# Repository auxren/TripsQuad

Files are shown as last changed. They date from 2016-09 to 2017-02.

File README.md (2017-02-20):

# TripsQuad
Eurorack quad wavefolder PCB files and Altium Project

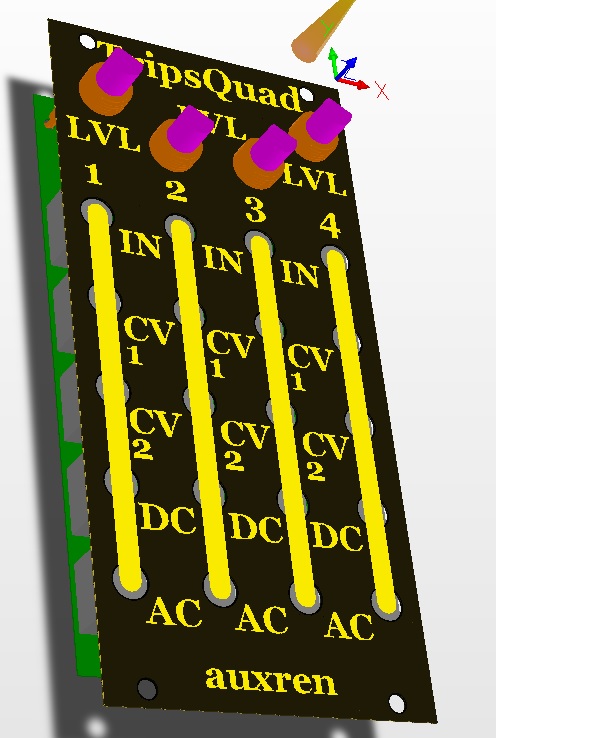
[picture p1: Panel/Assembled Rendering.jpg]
Optional Title


Mouser Cart: http://www.mouser.com/ProjectManager/ProjectDetail.aspx?AccessID=a7427f16d1 

The build is great for beginners learning how to surface mount solder. All the passives are 0805 and there is only 1 IC with a pretty wide pitch.

Note: The trim pots can go on either side; it's up to you. To adjust the trim pots, input a saw wave. Measure the voltage of the signal going in to a channel and adjust the corresponding channel's trim pot so the output has the same voltage.

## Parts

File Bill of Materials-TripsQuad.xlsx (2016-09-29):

Comment | Description | Designator | Supplier P/N | Supplier | Quantity
100pF | CAP 0.5pF 25V ±0.1pF 0805 (2012 Metric) Thickness 0.75mm SMD | C1, C2, C7, C8 | 80-C0805C101J5G (http://www.mouser.com/ProductDetail/Kemet/C0805C101J5GACTU/) | Mouser | 4
47uF | Aluminum Electrolytic Capacitor, 47 uF +/- 20%, 25 V, -55 to 105 degC, 2-Pin 5.3 x 5.3 x 6.1 mm SMD, RoHS, Tape and Reel | C3, C5, C9, C11 | 667-EEE-FT1E470AR | Mouser | 4
470nF | CAP 0.5pF 25V ±0.1pF 0805 (2012 Metric) Thickness 0.75mm SMD | C4, C6, C10, C12 | 581-080516C474K | Mouser | 4
10uF | Aluminum Electrolytic Capacitor, UD Series, Low Impedance, 10 uF, 25 V, + / - 20%, -55 to 105 degC, Chip Type, 4 x 5.8 mm D x L, Pb-Free, Reel | C13 | 810-C4532X7R1E106M | Mouser | 1
100nF | CAP 0.5pF 25V ±0.1pF 0805 (2012 Metric) Thickness 0.75mm SMD | C14, C15 | 581-FS051C104K4Z2A | Mouser | 2
20k | Trimming Potentiometer, 5K Ohm +/- 10%, -55 to 125 degC, 3-Pin 19.05 x 4.83 x 6.6 mm THD, Transparent Housing, RoHS | CH1, CH2, CH3, CH4 | 652-3006P-1-203-LF (http://www.mouser.com/ProductDetail/Bourns/3006P-1-203LF/?qs=sGAEpiMZZMvygUB3GLcD7rufck0TIBKyQNa0Y0kLqn4%3d) | Mouser | 4
1N4148W | Fast Switching Diode, 75 V, 150 mA, 2-Pin 2.7 x 1.6 x 1.25 mm SMD, Tape and Reel | D1, D2, D3, D4, D5, D6, D7, D8, D9, D10, D11, D12, D13, D14, D15, D16 | 833-1N4148W-TP (http://www.mouser.com/ProductDetail/Micro-Commercial-Components-MCC/1N4148W-TP/) | Mouser | 16
1N5819HW-7-F | 1.0 A Surface Mount Schottky Barrier Rectifier, 40 V, -65 to 125 degC, 2-Pin SOD-123 Package, RoHS, Tape and Reel | D17, D18 | 621-1N5819HW-F | Mouser | 2
Thonkicon jack |  | J1, J2, J3, J4, J5, J6, J7, J8, J9, J10, J11, J12, J13, J14, J15, J16, J17, J18, J19, J20 | Mouser: 858-P0915NEC15BR100K also works | Thonk, earthenvar, ect. | 20
100k Pots |  | P1, P2, P3, P4 |  | Thonk, earthenvar, ect. | 4
Header 5X2 | Header, 5-Pin, Dual row | P5 | 855-M20-9980545 (http://www.mouser.com/ProductDetail/Harwin/M20-9980545/) | Mouser | 1
1M5 | 1M5 0.125W 5% 0805 (2012 Metric) SMD | R1, R2, R3, R4, R13, R14, R17, R18, R20, R21, R29, R31 | 667-ERJ-6ENF1504V (http://www.mouser.com/ProductDetail/Panasonic/ERJ-6ENF1504V/?qs=sGAEpiMZZMtG0KNrPCHnjTg0x5DoQJ5P9A0uxp6gV1o%3d) | Mouser | 12
100K | 100K 0.125W 5% 0805 (2012 Metric) SMD | R5, R6, R15, R16, R19, R23, R30, R32 | 755-ESR10EZPJ104 (http://www.mouser.com/ProductDetail/ROHM-Semiconductor/ESR10EZPJ104/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) | Mouser | 8
330R | 330R 0.125W 5% 0805 (2012 Metric) SMD | R7, R8, R22, R25 | 755-ESR10EZPF3300 (http://www.mouser.com/ProductDetail/ROHM-Semiconductor/ESR10EZPF3300/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) | Mouser | 4
220K | 220K 0.125W 5% 0805 (2012 Metric) SMD | R9, R10, R24, R27 | 755-ESR10EZPF2203 (http://www.mouser.com/ProductDetail/ROHM-Semiconductor/ESR10EZPF2203/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) | Mouser | 4
150K | 150K 0.125W 5% 0805 (2012 Metric) SMD | R11, R12, R26, R28 | 755-ESR10EZPF1503 (http://www.mouser.com/ProductDetail/ROHM-Semiconductor/ESR10EZPF1503/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) | Mouser | 4
LM3900 |  | U1 | 595-LM3900DR (http://www.mouser.com/ProductDetail/Texas-Instruments/LM3900DR/?qs=sGAEpiMZZMtYFXwiBRPs06z3mIi0P6Vt) | Mouser | 1

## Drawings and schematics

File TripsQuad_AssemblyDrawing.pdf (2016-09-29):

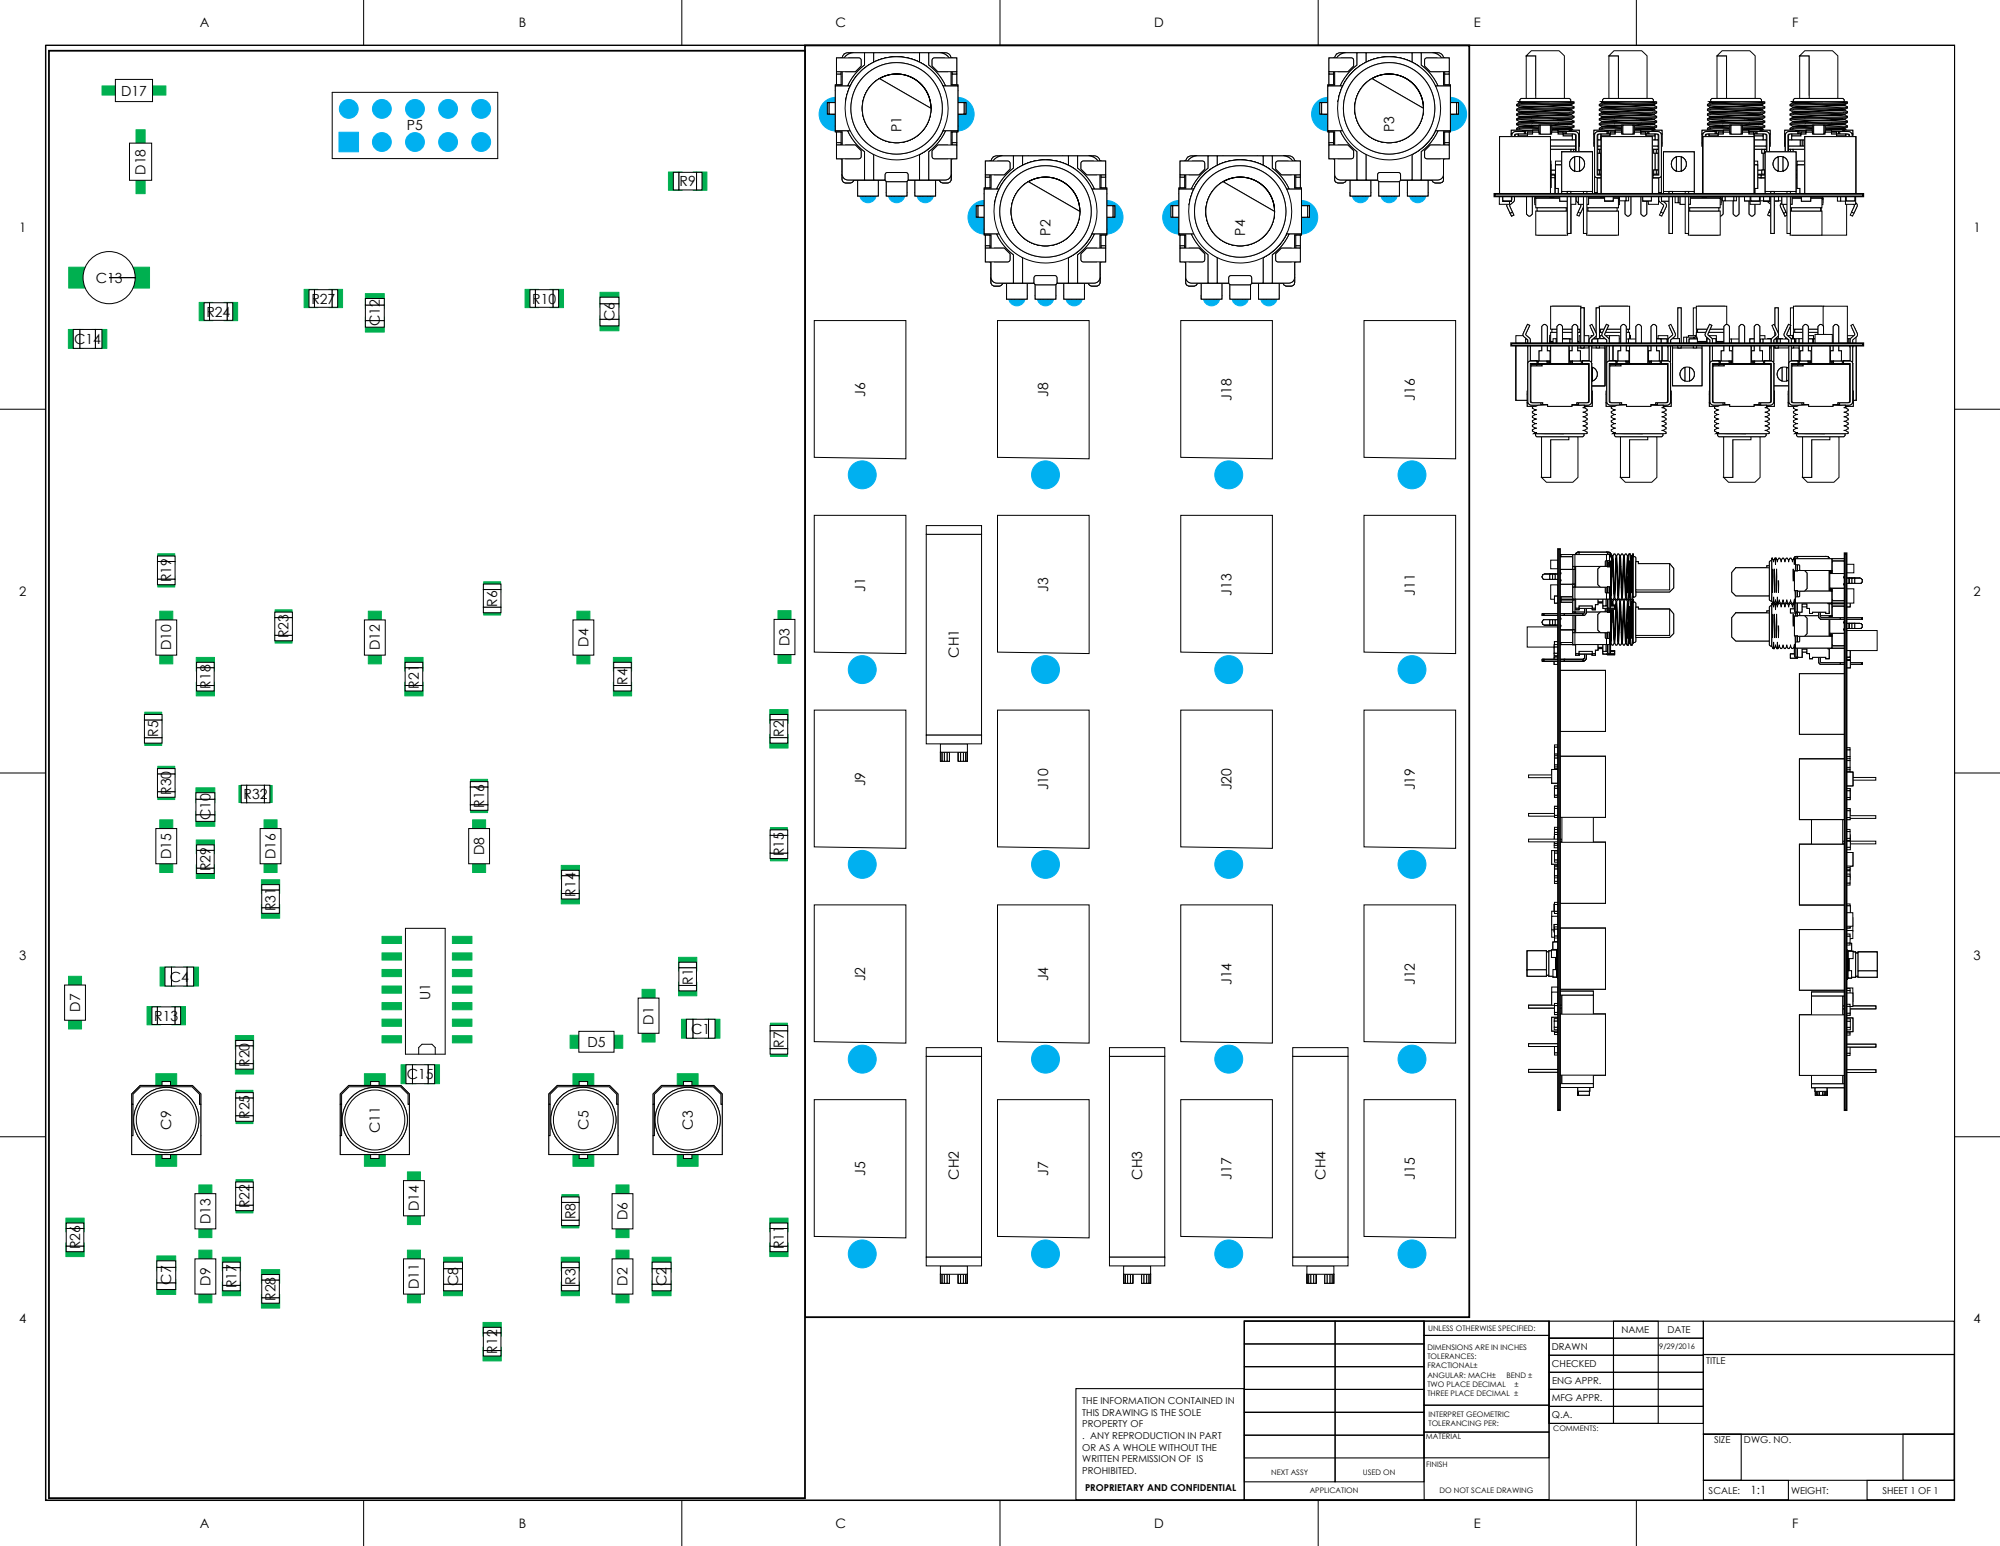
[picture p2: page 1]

DIMENSIONS ARE IN INCHES
TOLERANCES:
FRACTIONAL±
ANGULAR: MACH± BEND ±
TWO PLACE DECIMAL ±
THREE PLACE DECIMAL ±

THE INFORMATION CONTAINED IN
THIS DRAWING IS THE SOLE
PROPERTY OF
. ANY REPRODUCTION IN PART
OR AS A WHOLE WITHOUT THE
WRITTEN PERMISSION OF IS
PROHIBITED.
PROPRIETARY AND CONFIDENTIAL

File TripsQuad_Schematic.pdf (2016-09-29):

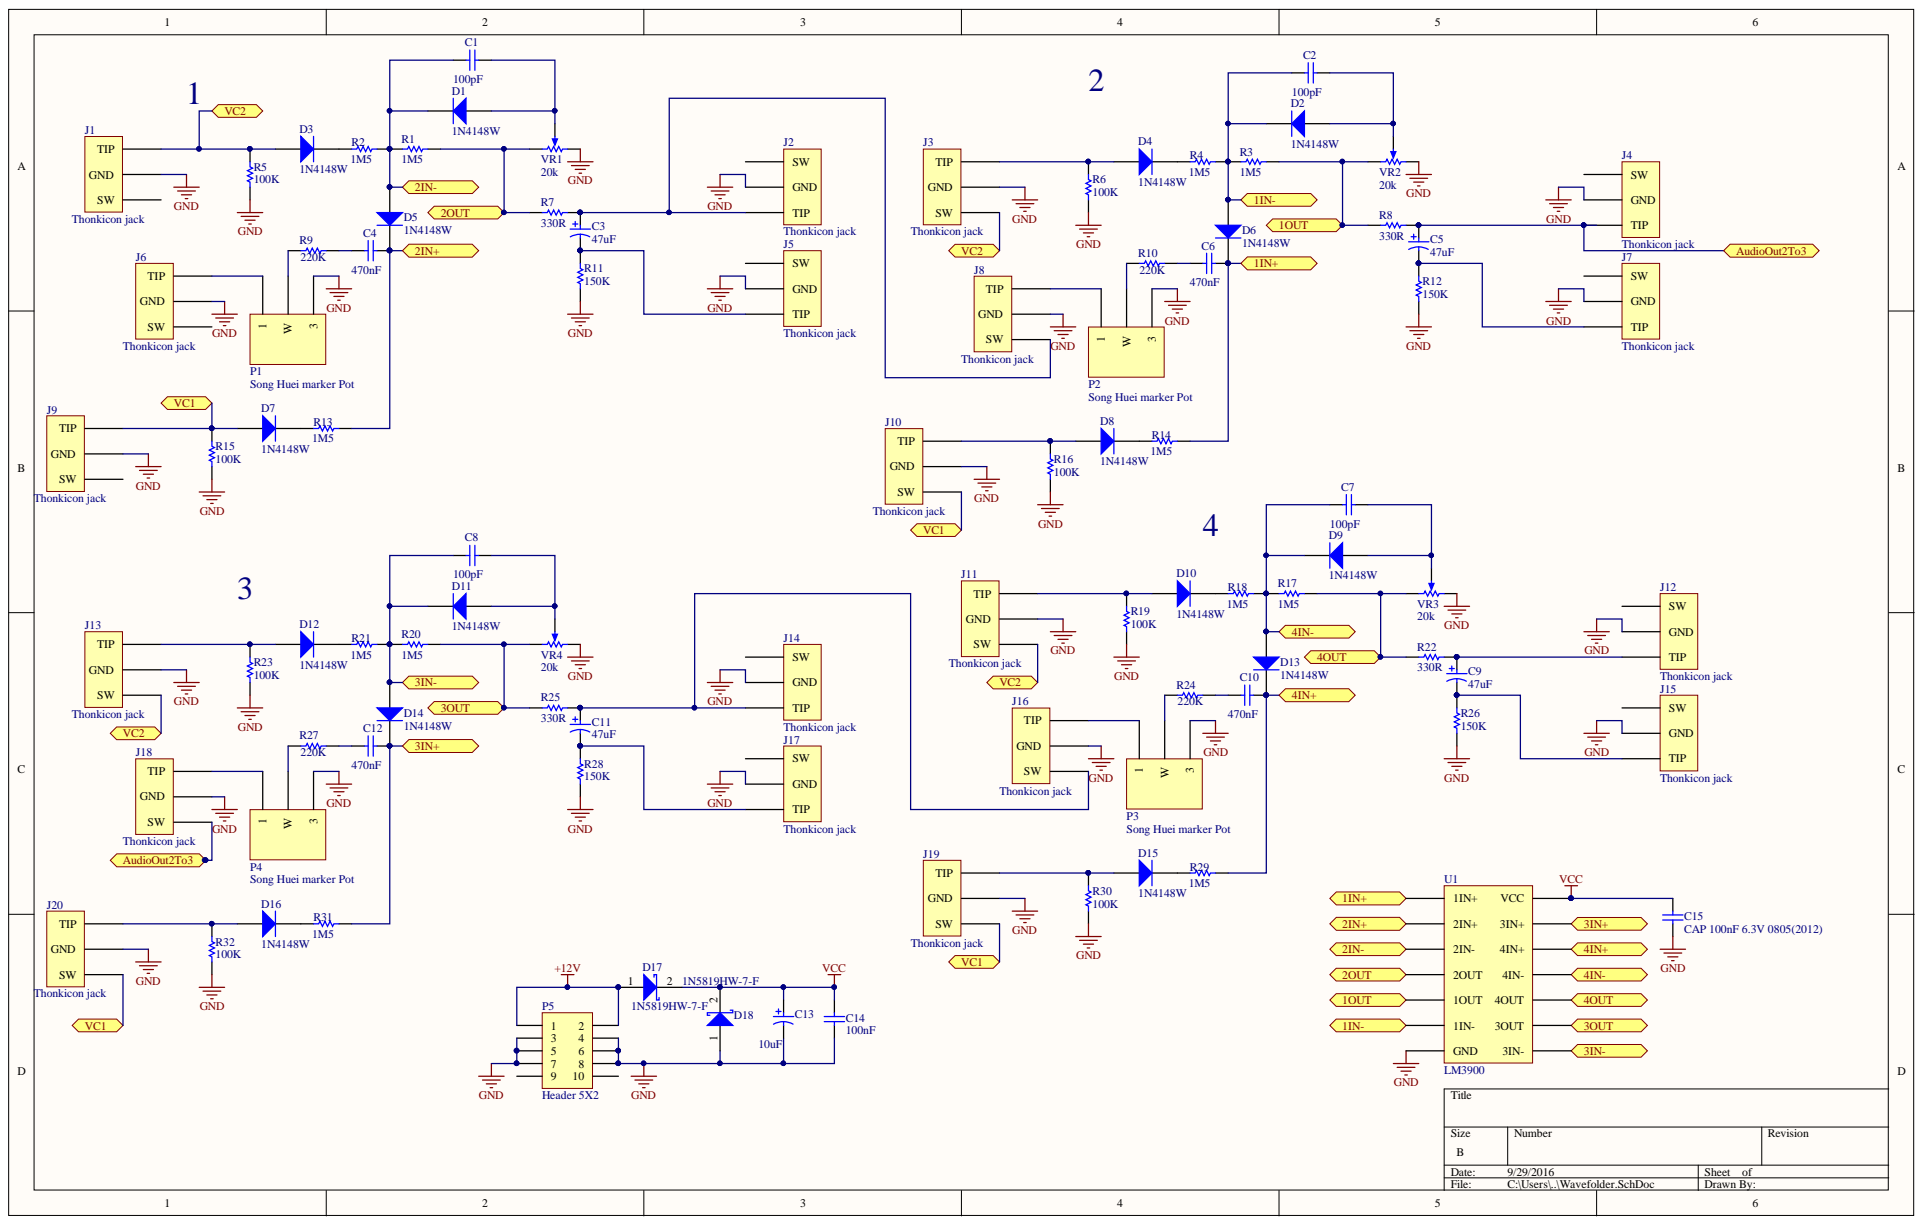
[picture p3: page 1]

Song Huei marker Pot

Size B | Number | Revision

Date: 9/29/2016 | Sheet of
File: C:\Users\..\Wavefolder.SchDoc | Drawn By:

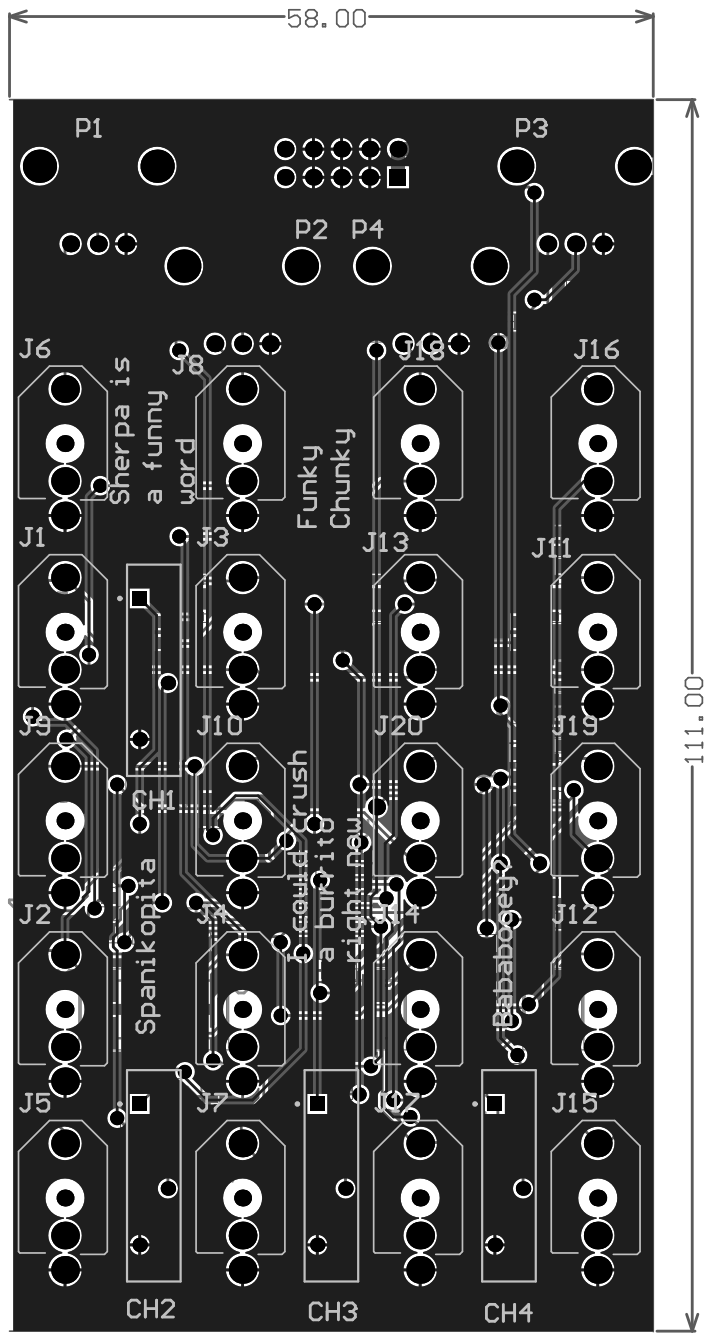
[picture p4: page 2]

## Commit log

2016-09-29 Initial Commit
    First Commit of Altium Project and Assembly Files
    [TripsQuad.GBL, TripsQuad.GBO, TripsQuad.GBP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]
2016-09-29 Added BOM
    BOM has been added
    [Bill of Materials-TripsQuad.xlsx]
2016-09-29 Added Panel Project and Files
    Added the Altium Project for the panel along with Fab Files
    [Sheet1.SchDoc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]
2016-09-29 Added Rendering
    Added rendering of PCB with Panel
2016-09-30 Enlarged pot holes
    Enlarged the holes for the pot in the panel since they were a bit too
    small.
    [TripsQuadIllustrator.PcbDoc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]
2016-09-30 Fixed pot hole size
    [TripsQuadIllustrator.PcbDoc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]
2016-10-13 Enlarged Panel Pot Holes
    Made dem pot holies biggahhh
    [TripsQuadPanel.PcbDoc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]
2016-11-22 Added Top Mask Layer
    Added contents to the top mask layer
    [TripsQuadPanel.GBL, TripsQuadPanel.GBO, TripsQuadPanel.GBP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]
2016-11-24 Added some obvious solder mask openings because fab place was being silly
    [LGA280C113P43X31_4900X3600X350.PcbLib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]
2016-11-24 renamed folder
    [TripsQuadPanel.GBL, TripsQuadPanel.GBO, TripsQuadPanel.GBP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]
2016-11-26 The board house is being strange so I had to add the cutouts to the solder mask layer too
    [TripsQuadPanel.PcbDoc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]
